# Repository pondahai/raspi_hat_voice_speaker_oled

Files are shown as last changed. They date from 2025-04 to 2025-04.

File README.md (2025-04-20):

# raspi_hat_voice_speaker_oled




## 簡介
這個Raspberry Pi HAT 整合了麥克風、音訊放大器和OLED螢幕，讓你輕鬆打造語音互動或多媒體應用！

## 設定驅動
在  
`/boot/firmware/config.txt`  
加入  
`dtoverlay=googlevoicehat-soundcard`  
重開機後就成為預設音訊輸入出裝置

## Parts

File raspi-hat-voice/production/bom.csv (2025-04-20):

Designator | Footprint | Quantity | Value | LCSC Part #
J1 | PinSocket_2x20_P2.54mm_Vertical | 1 | Raspberry_Pi_2_3
J2 | PinHeader_1x12_P2.54mm_Horizontal | 1 | Conn_01x12_Socket
M1 | DIP-6_W7.62mm_LongPads | 1 | inmp441
M2 | PinHeader_1x07_P2.54mm_Vertical | 1 | MAX98357A
M3 | PinHeader_1x04_P2.54mm_Vertical | 1 | OLED
SW1 | SW_SPST_B3U-3000P-B | 1 | 22
SW2 | SW_SPST_B3U-3000P-B | 1 | 24
SW3 | SW_SPST_B3U-3000P-B | 1 | 23
SW4 | SW_SPST_B3U-3000P-B | 1 | 26

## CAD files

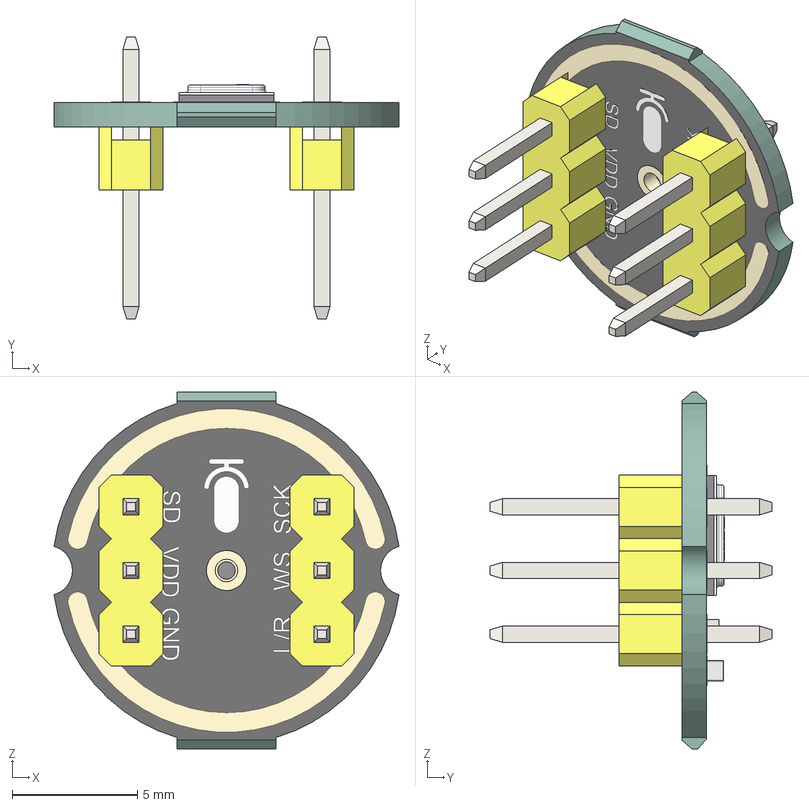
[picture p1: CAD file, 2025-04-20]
raspi-hat-voice/INMP441 I2S Microphone Module v15.step
13.8 x 11.2 x 14.2 mm
0603 Resistor

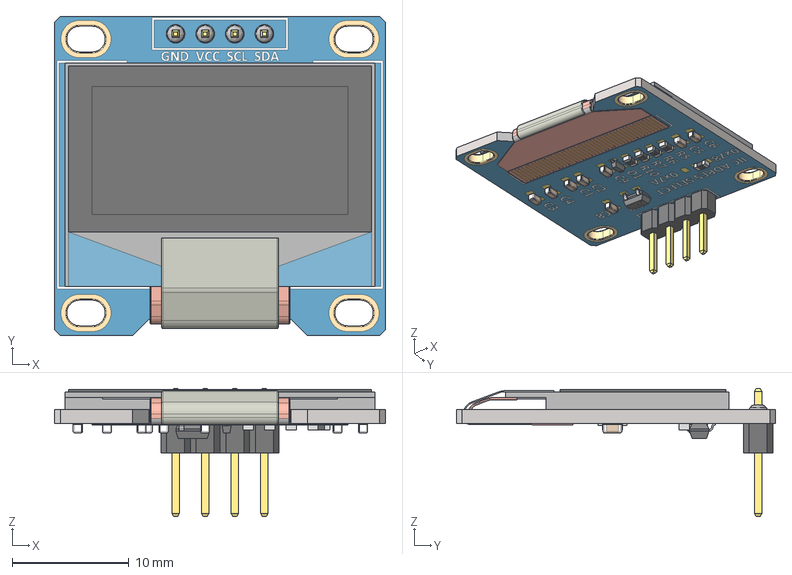
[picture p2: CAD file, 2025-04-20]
raspi-hat-voice/Pantalla OLED 0.96'' 128x64.stp
28.4 x 27.4 x 11.0 mm
SOT-23_TOR
RES_CR16_MTK_1 x 4
RES_CR16_MTK
SOD323F_DIO

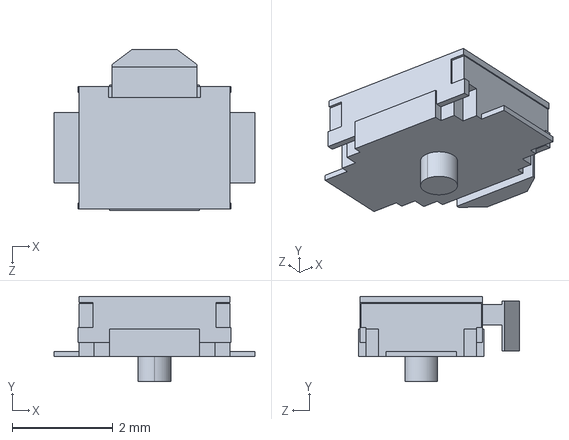
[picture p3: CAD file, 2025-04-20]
raspi-hat-voice/B3U-3000P-B--3DModel-STEP-56544.STEP
4.00 x 1.70 x 3.20 mm

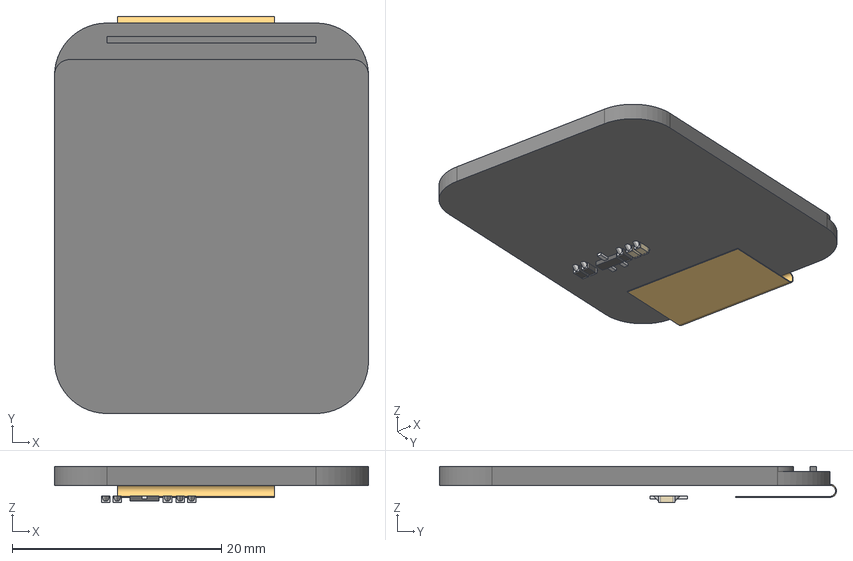
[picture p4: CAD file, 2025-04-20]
raspi-hat-voice/Display 1.69 ST7789V2_GLASS.step
30.0 x 37.9 x 3.44 mm
Display
R-0603 x 3
C-0603 x 2
U-0603

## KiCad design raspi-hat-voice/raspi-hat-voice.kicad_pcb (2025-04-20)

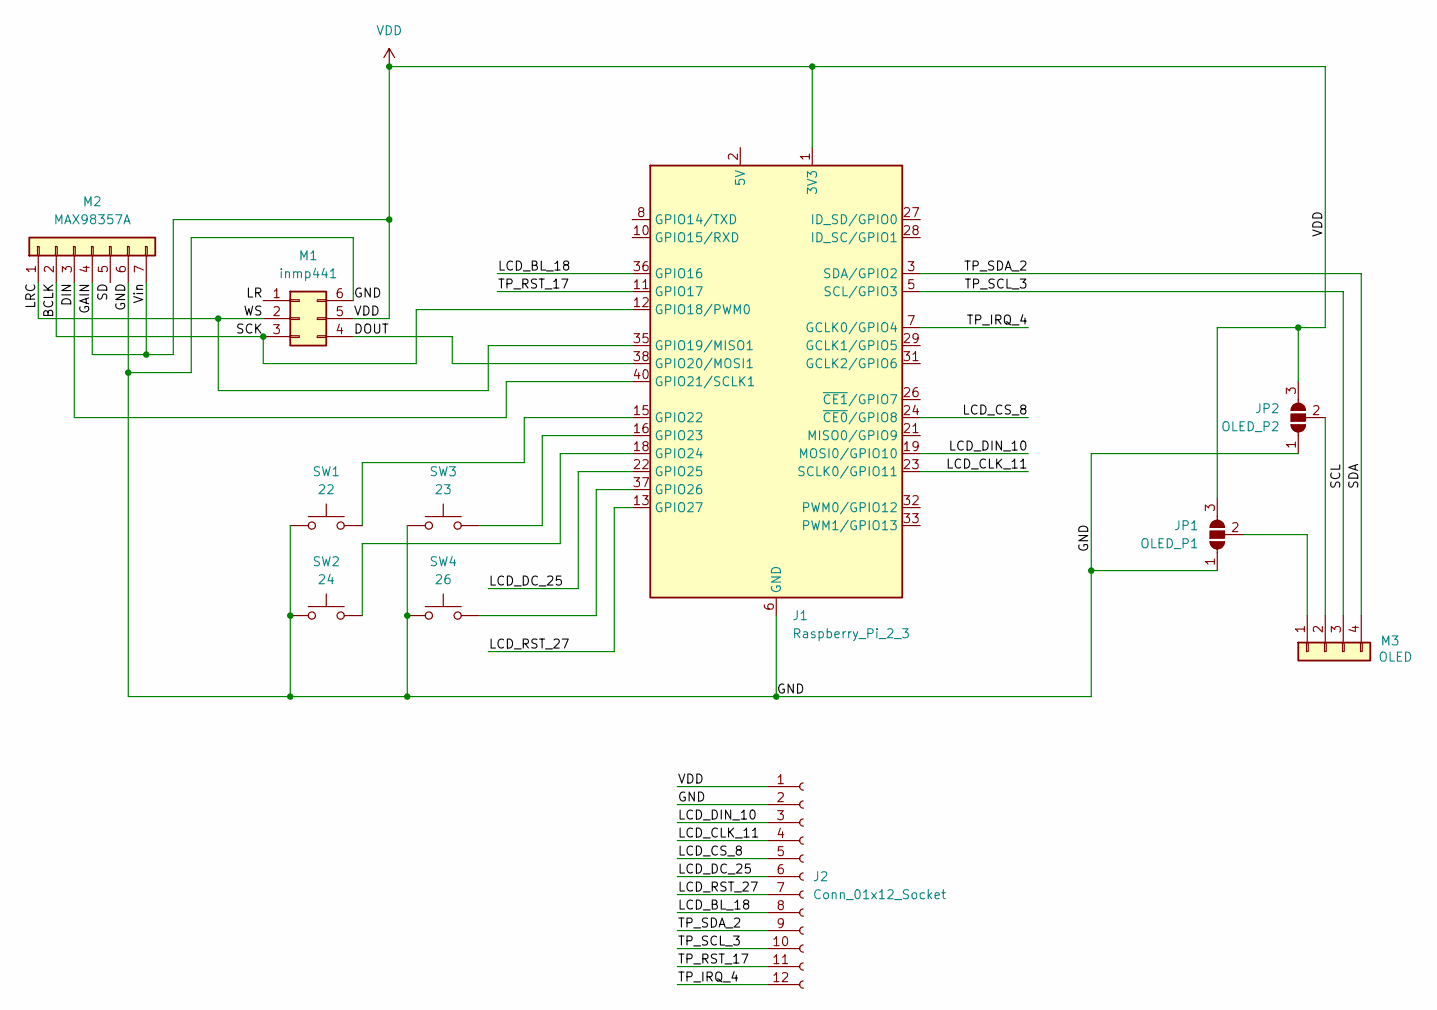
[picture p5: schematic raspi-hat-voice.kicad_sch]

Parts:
J1: Raspberry_Pi_2_3; PinSocket_2x20_P2.54mm_Vertical
J2: Conn_01x12_Socket; PinHeader_1x12_P2.54mm_Horizontal
JP1: OLED_P1; SolderJumper-3_P1.3mm_Open_RoundedPad1.0x1.5mm
JP2: OLED_P2; SolderJumper-3_P1.3mm_Open_RoundedPad1.0x1.5mm
M1: inmp441; DIP-6_W7.62mm_LongPads
M2: MAX98357A; PinHeader_1x07_P2.54mm_Vertical
M3: OLED; PinHeader_1x04_P2.54mm_Vertical
SW1: 22; SW_SPST_B3U-3000P-B
SW2: 24; SW_SPST_B3U-3000P-B
SW3: 23; SW_SPST_B3U-3000P-B
SW4: 26; SW_SPST_B3U-3000P-B

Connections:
/BCLK: J1.12 (GPIO18/PWM0), M1.3, M2.2
/DIN: J1.40 (GPIO21/SCLK1), M2.3
/DOUT: J1.38 (GPIO20/MOSI1), M1.4
/GND: J1.6 (GND), J1.9 (GND), J1.14 (GND), J1.20 (GND), J1.25 (GND), J1.30 (GND), J1.34 (GND), J1.39 (GND), J2.2, JP1.1 (A), JP2.1 (A), M1.6, M2.6, SW1.1, SW2.1, SW3.1, SW4.1
/LCD_BL_18: J1.36 (GPIO16), J2.8
/LCD_CLK_11: J1.23 (SCLK0/GPIO11), J2.4
/LCD_CS_8: J1.24 (~CE0/GPIO8), J2.5
/LCD_DC_25: J1.22 (GPIO25), J2.6
/LCD_DIN_10: J1.19 (MOSI0/GPIO10), J2.3
/LCD_RST_27: J1.13 (GPIO27), J2.7
/LR: M1.1
/LRC: J1.35 (GPIO19/MISO1), M1.2, M2.1
/SCL: J1.5 (SCL/GPIO3), J2.10, M3.3
/SD: M2.5
/SDA: J1.3 (SDA/GPIO2), J2.9, M3.4
/TP_IRQ_4: J1.7 (GCLK0/GPIO4), J2.12
/TP_RST_17: J1.11 (GPIO17), J2.11
unnamed: J1.2 (5V), J1.4 (5V)
unnamed: J1.15 (GPIO22), SW1.2
unnamed: J1.16 (GPIO23), SW3.2
unnamed: J1.18 (GPIO24), SW2.2
unnamed: J1.37 (GPIO26), SW4.2
unnamed: JP1.2 (C), M3.1
unnamed: JP2.2 (C), M3.2
VDD: J1.1 (3V3), J1.17 (3V3), J2.1, JP1.3 (B), JP2.3 (B), M1.5, M2.4, M2.7

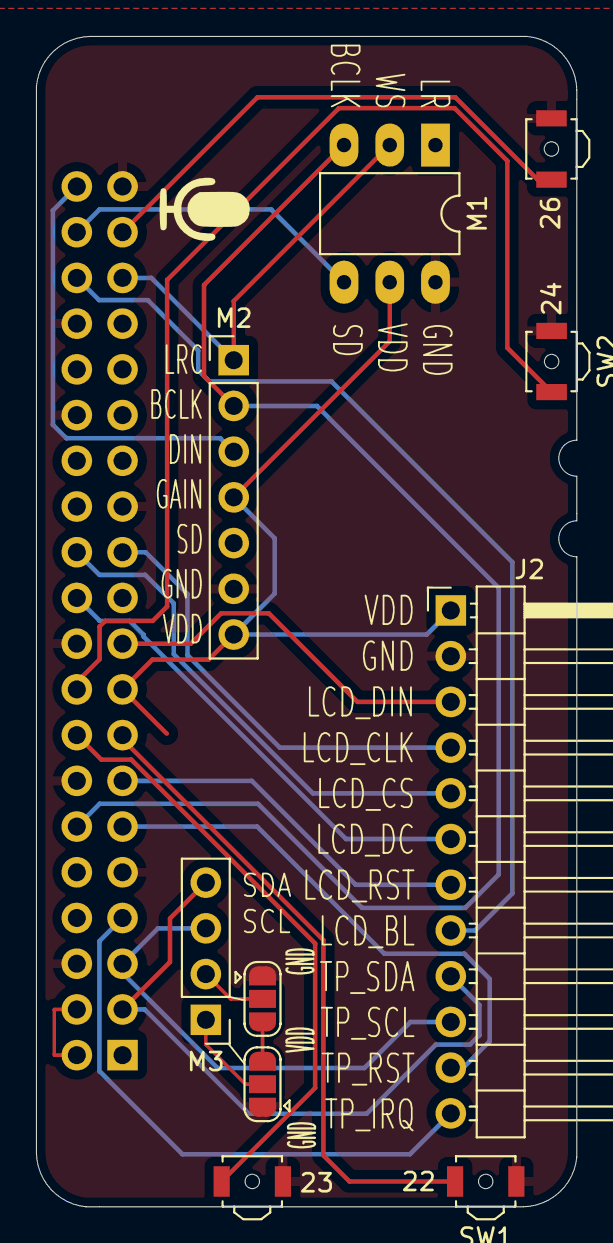
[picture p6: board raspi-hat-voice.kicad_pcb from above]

Board: 2 copper layers, 30.0 x 65.0 mm, 11 parts (1 on the bottom side), 23 nets.
